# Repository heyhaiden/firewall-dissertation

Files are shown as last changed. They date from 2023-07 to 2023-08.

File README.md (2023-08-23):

# Firewall Scout: Building a Digital Defensible Space with IoT

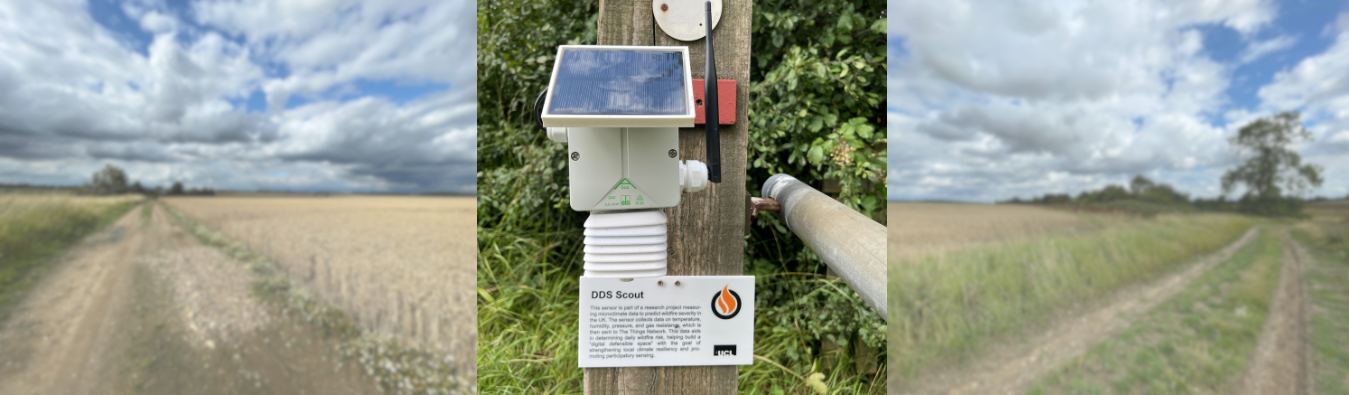
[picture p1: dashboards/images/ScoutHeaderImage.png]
Name


## Overview
The Firewall Scout project is a research initiative aimed at enhancing environmental monitoring and fire risk management within the UK's urban-rural interface (URI). This project introduces the concept of a "digital defensible space" - a protective barrier formed by a network of sensors that continuously monitor and analyze environmental variables contributing to fire risk. The goal is to enable precise assessment of potential fire hazards by generating a higher fidelity Fire Severity Index (FSI), thereby strengthening preventive measures and enhancing community resilience.

## Key Features
- **LoRa Connection Regulation:** Advanced LoRaWAN connection management with a smart retry mechanism to mitigate deployments on the edge of connectivity ranges. Energy-saving feature that puts the device in sleep mode if no connection is established.

- **Device Health and Data Transmission:** Comprehensive device health monitoring, including solar panel and battery status.

- **Downlink Messaging Control:** Dynamic behavior adjustment based on received downlink messages, including on-demand data collection feature for immediate response to changing conditions.

## Research Objectives
- Develop a low-cost sensing device to monitor environmental factors contributing to wildfire events.
- Assess the enhancement of wildfire detection and risk modeling in the UK's URI using a low-cost sensor network combined with participatory sensing.

## Technical Details

### Scout Node Design
- **Sensor Selection:** The BME688 sensor was chosen for its ability to measure temperature, humidity, pressure, and gas resistance. It demonstrated superior performance in dynamic conditions.
- **Hardware Components:** The Firewall Scout node operates on an Arduino MKRWAN 1310 with LoRaWAN connectivity. It's powered by a 3.7V 1000mAh rechargeable lithium polymer battery and optimized for ultra-low power usage.
- **Enclosure:** Components are housed in an IP65-rated plastic enclosure, ensuring weatherproof integrity. A custom-designed Stevenson screen model ensures adequate airflow for the sensor while protecting it from UV rays and direct sunlight.

### Arduino Libraries
- **BSEC Library:** Initially used for the BME688 sensor, this library from Bosch provides raw data readings and offers several power modes. However, due to compatibility issues, its use was discontinued.
- **Adafruit Library:** This library was employed for the development of a low-power version of the Scout node.
- **Arduino Low Power Library:** This library puts the microcontroller into deep sleep between duty cycles, drastically reducing power consumption during idle periods.

### Repository Contents
- **Code:** Reproducible code for the Firewall Scout project.
- **Sensor Calibration:** Calibration details for the sensors used.
- **Enclosure Designs:** Custom designs for the device enclosure.
- **Data:** Collected data used in the study.

## Deployment & Data Collection
Three Scout nodes were deployed from July - August, 2023. Two were placed in Fincham, Norfolk County, and one was placed in Stratford in the Greater London area. They were programmed to send data packets over a ten-minute duty cycle via LoRa radio to The Things Network (TTN). Data was collected in an InfluxDB database, hosted on a Raspberry Pi. Dashboards were constructed within InfluxDB and Grafana for data interpretation and visualization.

- **Grafana Snapshot:** []
- **Raw Dataset:** [https://drive.google.com/drive/folders/1qIohqHdbCPThrtIFe0_akVGIIpeAW5eb?usp=sharing]

## Conclusion
The Firewall Scout project represents a step forward in the field of IoT-enabled environmental monitoring and fire risk management. By leveraging technology, this research aims to provide a more comprehensive and accurate assessment of fire risks, ultimately contributing to safer and more resilient communities.

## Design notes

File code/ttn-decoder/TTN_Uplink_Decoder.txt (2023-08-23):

function Decoder(bytes, port) {
  var decoded = {};
  
  // Check if payload is an error message
  if (bytes[0] === 255) {
    decoded.error = String.fromCharCode.apply(null, bytes.slice(1));
    return decoded;
  }

  // decode payload
  var temperature = ((bytes[0] << 8) | bytes[1]) / 100.0;
  var humidity = ((bytes[2] << 8) | bytes[3]) / 100.0;
  var pressure = ((bytes[4] << 8) | bytes[5]) / 10.0;
  var gas_resistance = ((bytes[6] << 8) | bytes[7]) / 100.0;
  var statusBits = bytes[8];
  var packetCount = (bytes[9] << 8) | bytes[10];

  // determine solar status
  var solarStatusValue = statusBits & 0b00000011;
  var solar_status = "UNKNOWN";
  switch(solarStatusValue){
    case 0:
      solar_status = "OFF";
      break;
    case 1:
      solar_status = "ACTIVE";
      break;
  }

  // determine battery status
  var batteryStatusValue = (statusBits & 0b00001100) >> 2;
  var battery_status = "UNKNOWN";
  switch(batteryStatusValue){
    case 0:
      battery_status = "CHARGING";
      break;
    case 1:
      battery_status = "FULL";
      break;
    case 2:
      battery_status = "DRAINING";
      break;
  }

  // populate object
  decoded.temperature = Number(temperature.toFixed(2));
  decoded.humidity = Number(humidity.toFixed(2));
  decoded.pressure = Number(pressure.toFixed(2));
  decoded.gas_resistance = Number(gas_resistance.toFixed(2));
  decoded.solar_status = solar_status;
  decoded.battery_status = battery_status;
  decoded.packetCount = packetCount;

  return decoded;
}

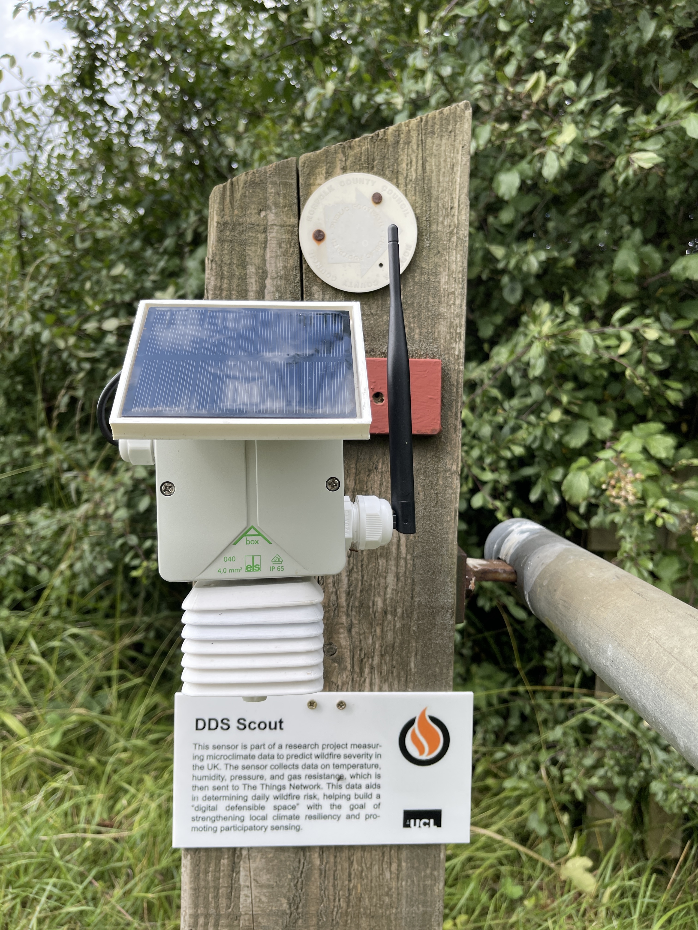
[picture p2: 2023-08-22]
dashboards/images/NatureReserve_Scout.JPG

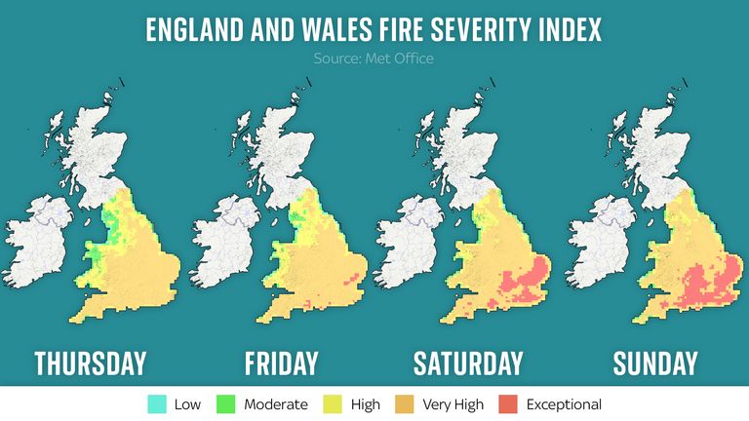
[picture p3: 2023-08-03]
dashboards/images/skynews-climate-fire-severity_5861295.jpg

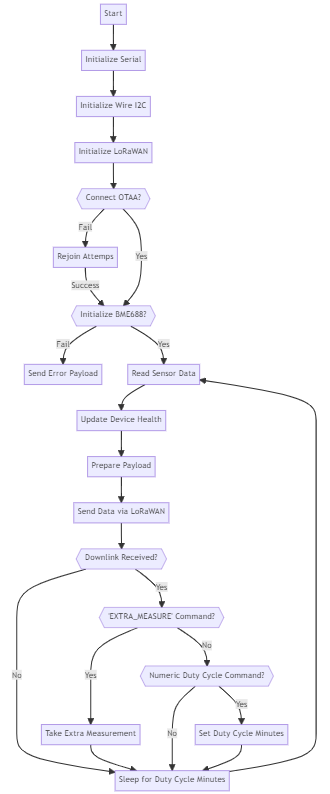
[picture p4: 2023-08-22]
dashboards/images/scout_program_flowchart.png

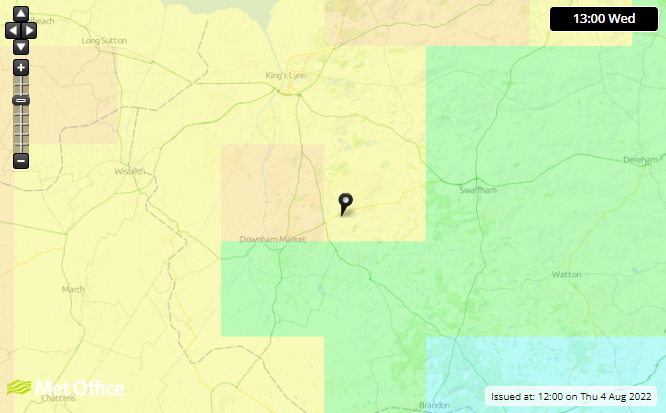
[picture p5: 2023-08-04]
dashboards/images/Fincham_FSI.png

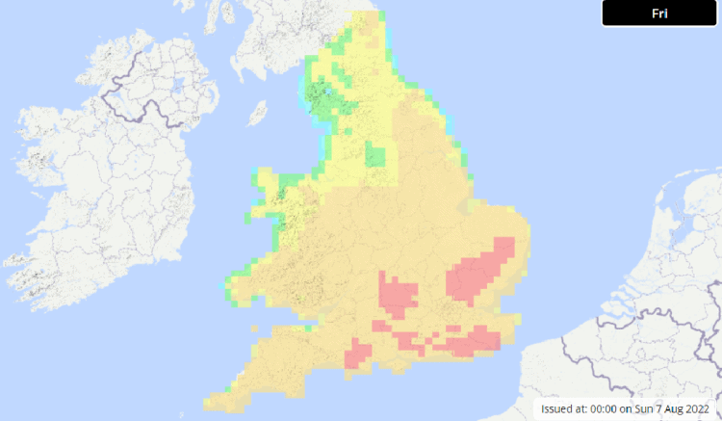
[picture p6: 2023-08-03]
dashboards/images/heatwave-map-met-office-750x437.png

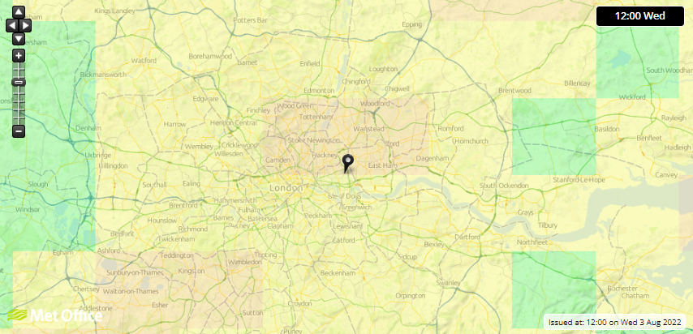
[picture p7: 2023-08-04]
dashboards/images/Stratford_QEOP_FSI.png

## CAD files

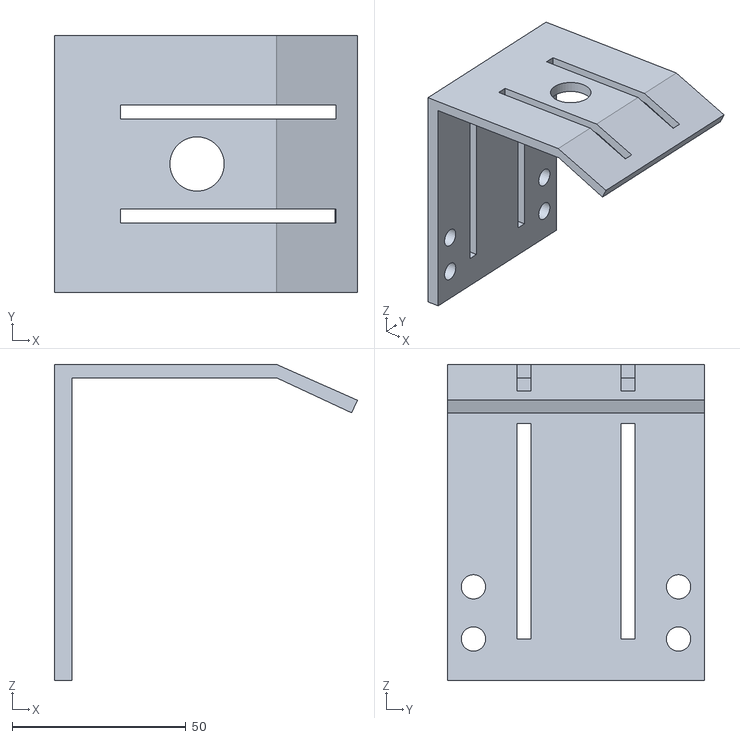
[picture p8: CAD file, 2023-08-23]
enclosure/Sensor_Mount_Thin.stl
87.1 x 74.0 x 91.0

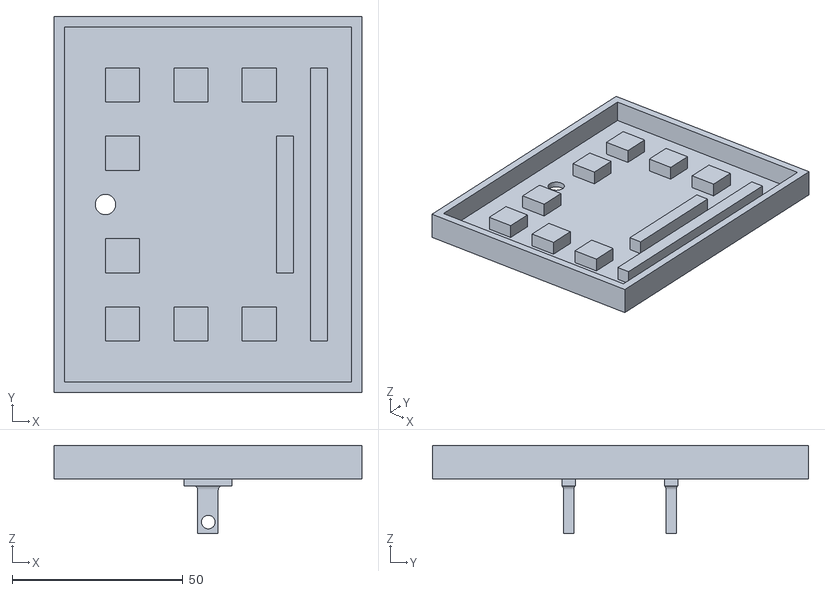
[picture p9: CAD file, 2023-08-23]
enclosure/SolarFrame_Back.stl
90.0 x 110.0 x 25.8

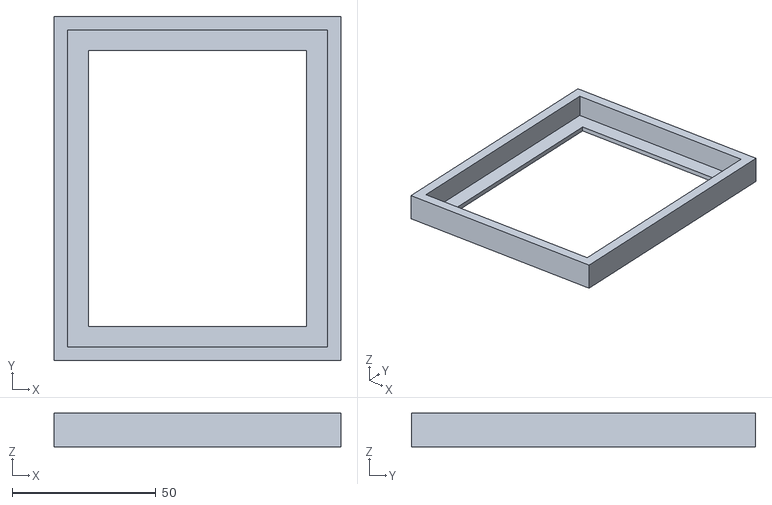
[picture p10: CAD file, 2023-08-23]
enclosure/SolarFrame_Cover.stl
100.0 x 120.0 x 11.8

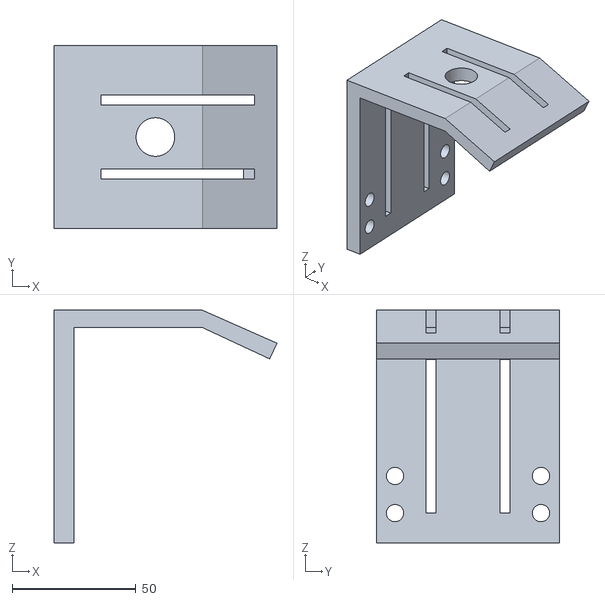
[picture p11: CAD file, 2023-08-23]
enclosure/Sensor_Mount.stl
90.1 x 74.0 x 94.0

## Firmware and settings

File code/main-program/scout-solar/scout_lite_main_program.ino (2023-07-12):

/* 
*****************************
FIREWALL: SCOUT LITE
SOLAR POWERED DEVICE
V4
*****************************

*/

#include <Arduino.h>
#include <MKRWAN.h>
#include <Adafruit_Sensor.h>
#include <Adafruit_BME680.h>
#include <ArduinoLowPower.h>
#include <Wire.h>
#include <LoRa.h>

//#include "ttn_config_secrets.h"
//#include "ttn_config_secrets_2.h"
#include "ttn_config_secrets_3.h"

#define PGOOD_PIN 1
#define CHG_PIN 2
#define CHARGE_SAMPLES 10
#define SAMPLE_DELAY 100
#define ERROR_FLAG 255
#define MAX_JOIN_ATTEMPTS 8
#define JOIN_RETRY_SLEEP_MINUTES 30
#define JOIN_RETRY_DELAY_MINUTES 2
#define LORA_CONNECTION_STABILIZATION_DELAY_SECONDS 5
#define ERROR_BLINK_COUNT 5

uint32_t DUTY_CYCLE_MINUTES = 10;

enum SolarStatus { OFF = 0, ACTIVE = 1 };
enum BatteryStatus { CHARGING = 0, FULL = 1, DRAINING = 2 };

class LoRaWAN {
public:
  LoRaModem modem;
  String appEui = SECRET_APP_EUI;
  String appKey = SECRET_APP_KEY;
  uint16_t packetCount = 0;

  void init();
  void handleDownlink();
  void sendData(byte* payload, size_t payloadSize);
};

class BME680Sensor {
public:
  Adafruit_BME680 bme;
  void init();
  void readAndSendData(LoRaWAN& lorawan);
};

class DeviceHealth {
public:
  SolarStatus solar_status;
  BatteryStatus battery_status;

  void update();
};

// Declare objects globally
LoRaWAN lorawan;
BME680Sensor sensor;
DeviceHealth deviceHealth;

void setup() {
  Serial.begin(115200);
  delay(1000);

  pinMode(PGOOD_PIN, INPUT);
  pinMode(CHG_PIN, INPUT);

  Wire.begin();

  lorawan.init();
  sensor.init();
}

void loop() {
  sensor.readAndSendData(lorawan);
  lorawan.handleDownlink();
  LowPower.sleep(DUTY_CYCLE_MINUTES * 60 * 1000);
}

void LoRaWAN::init() {
  int joinAttempts = 0;
  if (!modem.begin(EU868)) {
    Serial.println("Failed to start module");
    while (1) {}
  }

  Serial.print("Your module version is: ");
  Serial.println(modem.version());
  Serial.print("Your device EUI is: ");
  Serial.println(modem.deviceEUI());

  int connected = modem.joinOTAA(appEui, appKey);

  while (!connected && joinAttempts < MAX_JOIN_ATTEMPTS) {
    joinAttempts++;
    Serial.println("Not connected, trying again...");
    delay(JOIN_RETRY_DELAY_MINUTES * 60 * 1000);  // wait before next attempt
    connected = modem.joinOTAA(appEui, appKey);
  }

  if (connected) {
    Serial.println("Network joined!");
  } else {
    Serial.println("Failed to join network after several attempts. The device is going into a low power mode before trying again.");
    LowPower.sleep(JOIN_RETRY_SLEEP_MINUTES * 60 * 1000);  // sleep
    init();  // try to initialize the LoRaWAN connection again
  }

  modem.setADR(true);
  modem.minPollInterval(60);
  delay(LORA_CONNECTION_STABILIZATION_DELAY_SECONDS * 1000);  // wait to stabilize connection
}

void LoRaWAN::handleDownlink() {
  String receivedData;
  int i = 0;
  while (modem.available()) {
    receivedData += (char)modem.read();
    i++;
  }

  if (i == 0) {
    Serial.println("No downlink data received");
    return;
  }

  Serial.println("Received downlink data: " + receivedData);

  // If the received data is the "EXTRA_MEASURE" command, take an extra measurement
  if (receivedData == "EXTRA_MEASURE") {
    Serial.println("Extra measurement command received. Taking extra measurement...");
    BME680Sensor sensor;
    sensor.readAndSendData(*this);
  } else {
    // If the received data is a number, use it to set the duty cycle
    for (char c : receivedData) {
      if (!isDigit(c)) {
        Serial.println("Invalid data received for duty cycle. Ignoring...");
        return;
      }
    }
    DUTY_CYCLE_MINUTES = receivedData.toInt();  
  }
}

void LoRaWAN::sendData(byte* payload, size_t payloadSize) {
  int err;
  modem.beginPacket();
  modem.write(payload, payloadSize);
  err = modem.endPacket(true);

  if (err > 0) {
    packetCount++;
    Serial.println("LoRa Packet sent");
  } else {
    Serial.println("Error sending LoRa Packet");
  }
}

void BME680Sensor::init() {
  if (!bme.begin(0x76)) {
    Serial.println("Could not find a valid BME680 sensor, check wiring!");
    errorLed(ERROR_BLINK_COUNT);
    LoRaWAN lorawan;
    String errorMessage = "Error: Could not find a valid BME680 sensor.";
    byte payload[errorMessage.length() + 1];
    payload[0] = ERROR_FLAG;
    memcpy(payload + 1, errorMessage.c_str(), errorMessage.length());
    lorawan.sendData(payload, sizeof(payload));
    LowPower.sleep(DUTY_CYCLE_MINUTES * 60 * 1000);
  }

  bme.setTemperatureOversampling(BME680_OS_8X);
  bme.setHumidityOversampling(BME680_OS_8X);
  bme.setPressureOversampling(BME680_OS_4X);
  bme.setIIRFilterSize(BME680_FILTER_SIZE_3);
  bme.setGasHeater(320, 150);

  Serial.println("BME680 sensor initialized and calibrated.");
}

void BME680Sensor::readAndSendData(LoRaWAN& lorawan) {
  unsigned long endTime = bme.beginReading();
  if (endTime == 0) {
    Serial.println("Failed to begin reading");
    return;
  }

  DeviceHealth deviceHealth;
  deviceHealth.update();

  if (!bme.endReading()) {
    Serial.println("Failed to complete reading");
    return;
  }

  int temperature = bme.temperature * 100.0;
  int humidity = bme.humidity * 100.0;
  int pressure = 10 * (bme.pressure / 100.0);
  int gas_resistance = bme.gas_resistance / 10.0;

  byte payload[11];
  payload[0] = highByte(temperature);
  payload[1] = lowByte(temperature);
  payload[2] = highByte(humidity);
  payload[3] = lowByte(humidity);
  payload[4] = highByte(pressure);
  payload[5] = lowByte(pressure);
  payload[6] = highByte(gas_resistance);
  payload[7] = lowByte(gas_resistance);
  payload[8] = (deviceHealth.battery_status << 2) | deviceHealth.solar_status;
  payload[9] = highByte(lorawan.packetCount);
  payload[10] = lowByte(lorawan.packetCount);

  lorawan.sendData(payload, sizeof(payload));
}

void DeviceHealth::update() {
  int pgood_count = 0;
  int chg_count = 0;

  for (int i = 0; i < CHARGE_SAMPLES; i++) {
    pgood_count += digitalRead(PGOOD_PIN) == LOW ? 1 : 0;
    chg_count += digitalRead(CHG_PIN) == LOW ? 1 : 0;
    delay(SAMPLE_DELAY);
  }

  if (pgood_count > CHARGE_SAMPLES / 2) {
    solar_status = ACTIVE;
    Serial.println("Solar panel is ACTIVE.");
  } else {
    solar_status = OFF;
    Serial.println("Solar panel is OFF.");
  }

  if (chg_count > CHARGE_SAMPLES / 2) {
    battery_status = CHARGING;
    Serial.println("Battery is CHARGING.");
    if (solar_status == OFF) {
      solar_status = ACTIVE;
      Serial.println("Correction: Solar panel is ACTIVE.");
    }
  } else {
    if (solar_status == ACTIVE) {
      battery_status = FULL;
      Serial.println("Battery is FULL.");
    } else {
      battery_status = DRAINING;
      Serial.println("Battery is DRAINING.");
    }
  }
  Serial.println();
}

void errorLed(int blinkCount) {
  pinMode(LED_BUILTIN, OUTPUT);
  for (int i = 0; i < blinkCount; i++) {
    digitalWrite(LED_BUILTIN, HIGH);
    delay(100);
    digitalWrite(LED_BUILTIN, LOW);
    delay(100);
  }
}

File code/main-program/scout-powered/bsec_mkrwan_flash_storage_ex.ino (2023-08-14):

#include <FlashStorage.h>
#include "bsec.h"
/* Configure the BSEC library with information about the sensor
    18v/33v = Voltage at Vdd. 1.8V or 3.3V
    3s/300s = BSEC operating mode, BSEC_SAMPLE_RATE_LP or BSEC_SAMPLE_RATE_ULP
    4d/28d = Operating age of the sensor in days
    generic_18v_3s_4d
    generic_18v_3s_28d
    generic_18v_300s_4d
    generic_18v_300s_28d
    generic_33v_3s_4d
    generic_33v_3s_28d
    generic_33v_300s_4d
    generic_33v_300s_28d
*/

// Create a structure to hold the state data
struct BsecState {
  uint8_t state[BSEC_MAX_STATE_BLOB_SIZE];
};

// Initialize flash storage with the BsecState structure
FlashStorage(flashStore, BsecState);

const uint8_t bsec_config_iaq[] = {
#include "config/generic_33v_3s_4d/bsec_iaq.txt"
};

#define STATE_SAVE_PERIOD	UINT32_C(360 * 60 * 1000) // 360 minutes - 4 times a day

// Helper functions declarations
void checkIaqSensorStatus(void);
void errLeds(void);
void loadState(void);
void updateState(void);

// Create an object of the class Bsec
Bsec iaqSensor;
uint8_t bsecState[BSEC_MAX_STATE_BLOB_SIZE] = {0};
uint16_t stateUpdateCounter = 0;
uint32_t millisOverflowCounter = 0;
uint32_t lastTime = 0;

String output;

// Entry point for the example
void setup(void)
{
  Serial.begin(115200);
  delay(1000);
  pinMode(LED_BUILTIN, OUTPUT);
  iaqSensor.begin(BME68X_I2C_ADDR_LOW, Wire);
  output = "\nBSEC library version " + String(iaqSensor.version.major) + "." + String(iaqSensor.version.minor) + "." + String(iaqSensor.version.major_bugfix) + "." + String(iaqSensor.version.minor_bugfix);
  Serial.println(output);
  
  checkIaqSensorStatus();

  iaqSensor.setConfig(bsec_config_iaq);
  checkIaqSensorStatus();

  loadState();

  bsec_virtual_sensor_t sensorList[13] = {
    BSEC_OUTPUT_IAQ,
    BSEC_OUTPUT_STATIC_IAQ,
    BSEC_OUTPUT_CO2_EQUIVALENT,
    BSEC_OUTPUT_BREATH_VOC_EQUIVALENT,
    BSEC_OUTPUT_RAW_TEMPERATURE,
    BSEC_OUTPUT_RAW_PRESSURE,
    BSEC_OUTPUT_RAW_HUMIDITY,
    BSEC_OUTPUT_RAW_GAS,
    BSEC_OUTPUT_STABILIZATION_STATUS,
    BSEC_OUTPUT_RUN_IN_STATUS,
    BSEC_OUTPUT_SENSOR_HEAT_COMPENSATED_TEMPERATURE,
    BSEC_OUTPUT_SENSOR_HEAT_COMPENSATED_HUMIDITY,
    BSEC_OUTPUT_GAS_PERCENTAGE
  };

  iaqSensor.updateSubscription(sensorList, 13, BSEC_SAMPLE_RATE_LP);
  checkIaqSensorStatus();

  // Print the header
  output = "Timestamp [ms], IAQ, IAQ accuracy, Static IAQ, CO2 equivalent, breath VOC equivalent, raw temp[°C], pressure [hPa], raw relative humidity [%], gas [Ohm], Stab Status, run in status, comp temp[°C], comp humidity [%], gas percentage";
  Serial.println(output);
}

// Function that is looped forever
void loop(void)
{
  unsigned long time_trigger = millis();
  if (iaqSensor.run()) { // If new data is available
    digitalWrite(LED_BUILTIN, LOW);
    output = String(time_trigger);
    output += ", " + String(iaqSensor.iaq);
    output += ", " + String(iaqSensor.iaqAccuracy);
    output += ", " + String(iaqSensor.staticIaq);
    output += ", " + String(iaqSensor.co2Equivalent);
    output += ", " + String(iaqSensor.breathVocEquivalent);
    output += ", " + String(iaqSensor.rawTemperature);
    output += ", " + String(iaqSensor.pressure);
    output += ", " + String(iaqSensor.rawHumidity);
    output += ", " + String(iaqSensor.gasResistance);
    output += ", " + String(iaqSensor.stabStatus);
    output += ", " + String(iaqSensor.runInStatus);
    output += ", " + String(iaqSensor.temperature);
    output += ", " + String(iaqSensor.humidity);
    output += ", " + String(iaqSensor.gasPercentage);
    Serial.println(output);
    digitalWrite(LED_BUILTIN, HIGH);
    updateState();
  } else {
    checkIaqSensorStatus();
  }
}

// Helper function definitions
void checkIaqSensorStatus(void)
{
  if (iaqSensor.bsecStatus != BSEC_OK) {
    if (iaqSensor.bsecStatus < BSEC_OK) {
      output = "BSEC error code : " + String(iaqSensor.bsecStatus);
      Serial.println(output);
      for (;;)
        errLeds(); /* Halt in case of failure */
    } else {
      output = "BSEC warning code : " + String(iaqSensor.bsecStatus);
      Serial.println(output);
    }
  }

  if (iaqSensor.bme68xStatus != BME68X_OK) {
    if (iaqSensor.bme68xStatus < BME68X_OK) {
      output = "BME68X error code : " + String(iaqSensor.bme68xStatus);
      Serial.println(output);
      for (;;)
        errLeds(); /* Halt in case of failure */
    } else {
      output = "BME68X warning code : " + String(iaqSensor.bme68xStatus);
      Serial.println(output);
    }
  }
}

void errLeds(void)
{
  pinMode(LED_BUILTIN, OUTPUT);
  digitalWrite(LED_BUILTIN, HIGH);
  delay(100);
  digitalWrite(LED_BUILTIN, LOW);
  delay(100);
}

void loadState(void)
{
  BsecState storedState = flashStore.read();
  if (storedState.state[0] == BSEC_MAX_STATE_BLOB_SIZE) {
    Serial.println("Reading state from flash memory");
    for (uint8_t i = 0; i < BSEC_MAX_STATE_BLOB_SIZE; i++) {
      bsecState[i] = storedState.state[i];
      Serial.println(bsecState[i], HEX);
    }
    iaqSensor.setState(bsecState);
    checkIaqSensorStatus();
  }
}

void updateState(void)
{
  bool update = false;
  if (stateUpdateCounter == 0) {
    /* First state update when IAQ accuracy is >= 3 */
    if (iaqSensor.iaqAccuracy >= 1) {
      update = true;
      stateUpdateCounter++;
    }
  } else {
    /* Update every STATE_SAVE_PERIOD minutes */
    if ((stateUpdateCounter * STATE_SAVE_PERIOD) < millis()) {
      update = true;
      stateUpdateCounter++;
    }
  }

  if (update) {
    iaqSensor.getState(bsecState);
    checkIaqSensorStatus();
    Serial.println("Writing state to flash memory");

    BsecState newState;
    for (uint8_t i = 0; i < BSEC_MAX_STATE_BLOB_SIZE ; i++) {
      newState.state[i] = bsecState[i];
      Serial.println(bsecState[i], HEX);
    }

    flashStore.write(newState);
  }
}

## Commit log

2023-07-10 Fixed charging status payload
    [scout_lite_main_program.ino]
2023-07-10 Fixed packet count value freeze
    [scout_lite_main_program.ino]
2023-08-22 Upload Flowchart
2023-08-23 Add enclosure files
    [Sensor_Mount.stl, Sensor_Mount_Thin.stl, SolarFrame_Back.stl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]
